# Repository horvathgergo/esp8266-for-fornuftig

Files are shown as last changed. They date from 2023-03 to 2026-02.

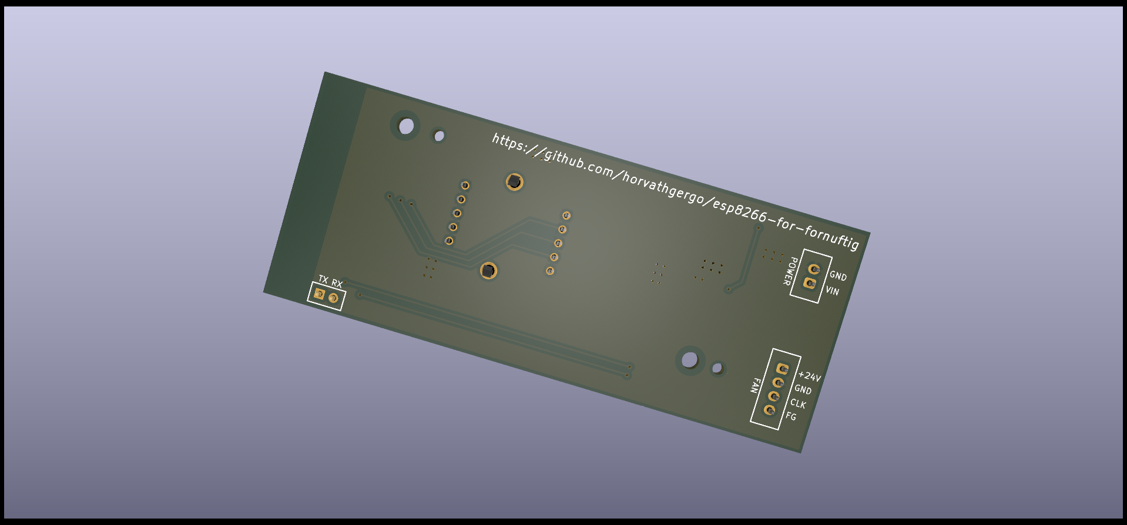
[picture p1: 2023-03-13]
Hardware/3D-model/3d-back-sw.png

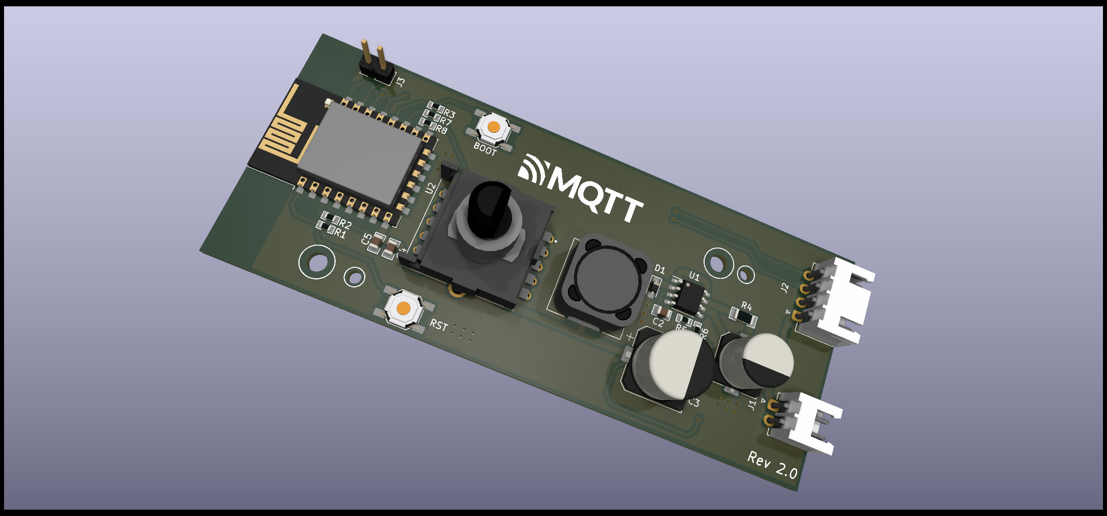
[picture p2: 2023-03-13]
Hardware/3D-model/3d-front-sw.png

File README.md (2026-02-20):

Newer version of the board based on an ESP32-C6 chip is available here: https://github.com/horvathgergo/esp32c6-for-fornuftig

# Smart Air Purifier (Project Fornuftig)

Custom PCB based on ESP12-F (ESP8266) wifi module that serves as a smart controller for IKEA Fornuftig Air Purifiers. It's embedded microcontroller enables you to incorporate your device to home automation systems (preferably to Home Assistant) or control it via custom mobile applications as it enjoys support from wide variety of firmwares. This project has been implemented in KiCad (hardware) and in Micropython (sofware).

About IKEA Fornuftig: It's a compact, 31x45 cm air purifier launched in the market around 2020. It effectively cleans the indoor air from harmful PM2.5 particles and pollen for a reasonable price (approx. EUR60). The device is optimised for medium-sized bedrooms and has three fan speed. 

Current status of the development: **Finalized**

Hardware: 
* [x] Schematic
* [x] Layout
* [x] BOM, CPL
* [x] 3D model 
* [x] Testing (v1.1 w/o switch)

Software:
* [x] MicroPython

## Hardware



PCB is a bit larger than the original one (98x40 mm) with mounting holes placed on it, thus it is supposed to fit just fine inside the plastic housing. Power supply of the fan is +24V, 0.8A. The board has a MC34063DR switching voltage regulator that provides the necessary power (+3v3, avg 70mA, peak >500mA) for the wifi module. This version (v2.0) of the board is designed with a rotary switch. To avoid unnecessary costs and save some space on the board physical filter reset button is not incorporated in this version as this function can be easily achieved through software side. 

The Purifier has a 4-pin PWM fan with +24VDC, 0.5A. The pins are power, ground, clk, fg. Clk is a control pin and fg is the tacho pin for feedback purposes. The fan operates with a constant duty cycle of 50% and variable frequency between ca. 1-300Hz.

MCU programming: the board supports only UART programming via TX, RX pin headers (as no USB interface), thus USB to TTL converter is necessary to upload your firmware. It is recommended to supply the module via VIN and GND pins during initial setup. It is compatible with +5-24V supply (note: in serial bootloader mode you need to supply at least +5V. Standard +3v3 won't work as you may experience some voltage drop via the buck converter so make sure to provide enough voltage during flashing. Supplying +5V won't hurt the ESP as the VIN pin of the board is not directly connected to chip). Boot button is located on the right side of the wifi module.

Tested first version of the board w/o rotary switch:



BOM: Most of the chosen components are considered to be basic/standard parts at LCSC, however there are some extended components on the list (two large caps, inductor, esp, jst connectors and uart pin headers).

## Software

The software for Fornuftig has been developed in Micropython. It enables the device to be controlled via mqtt while exploits Home Assistant mqtt autodiscovery features that provides with a smooth (almost zero config) setup process.

More detailed description is available in this repo: https://github.com/horvathgergo/uPurifier

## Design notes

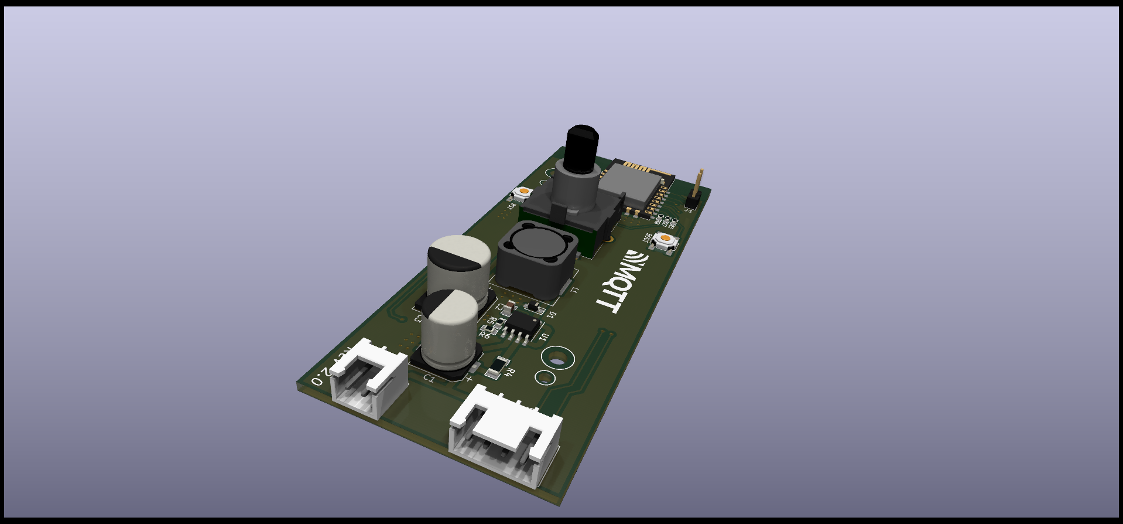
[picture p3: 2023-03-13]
Hardware/3D-model/3d-front2-sw.png

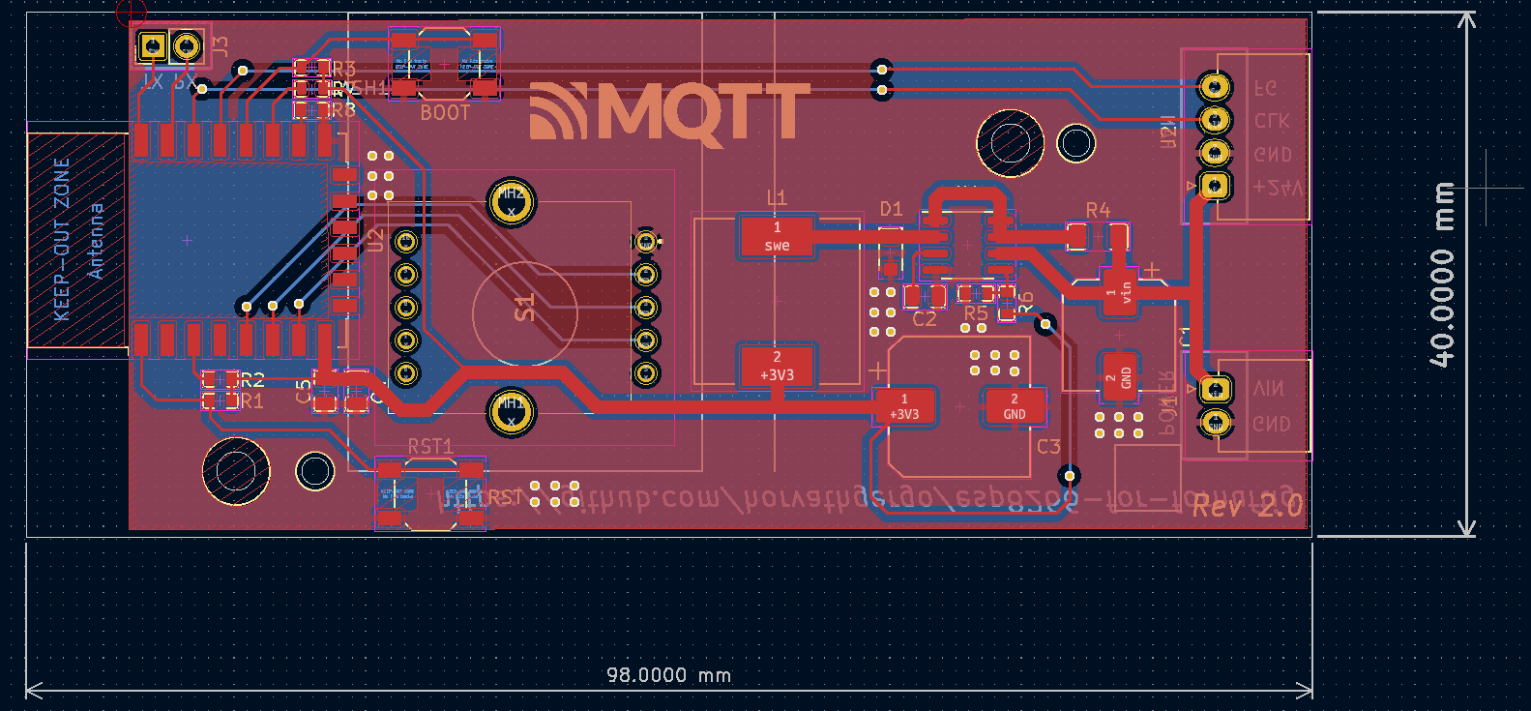
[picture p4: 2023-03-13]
Hardware/Air-Purifier-Fornuftig-Layout.png

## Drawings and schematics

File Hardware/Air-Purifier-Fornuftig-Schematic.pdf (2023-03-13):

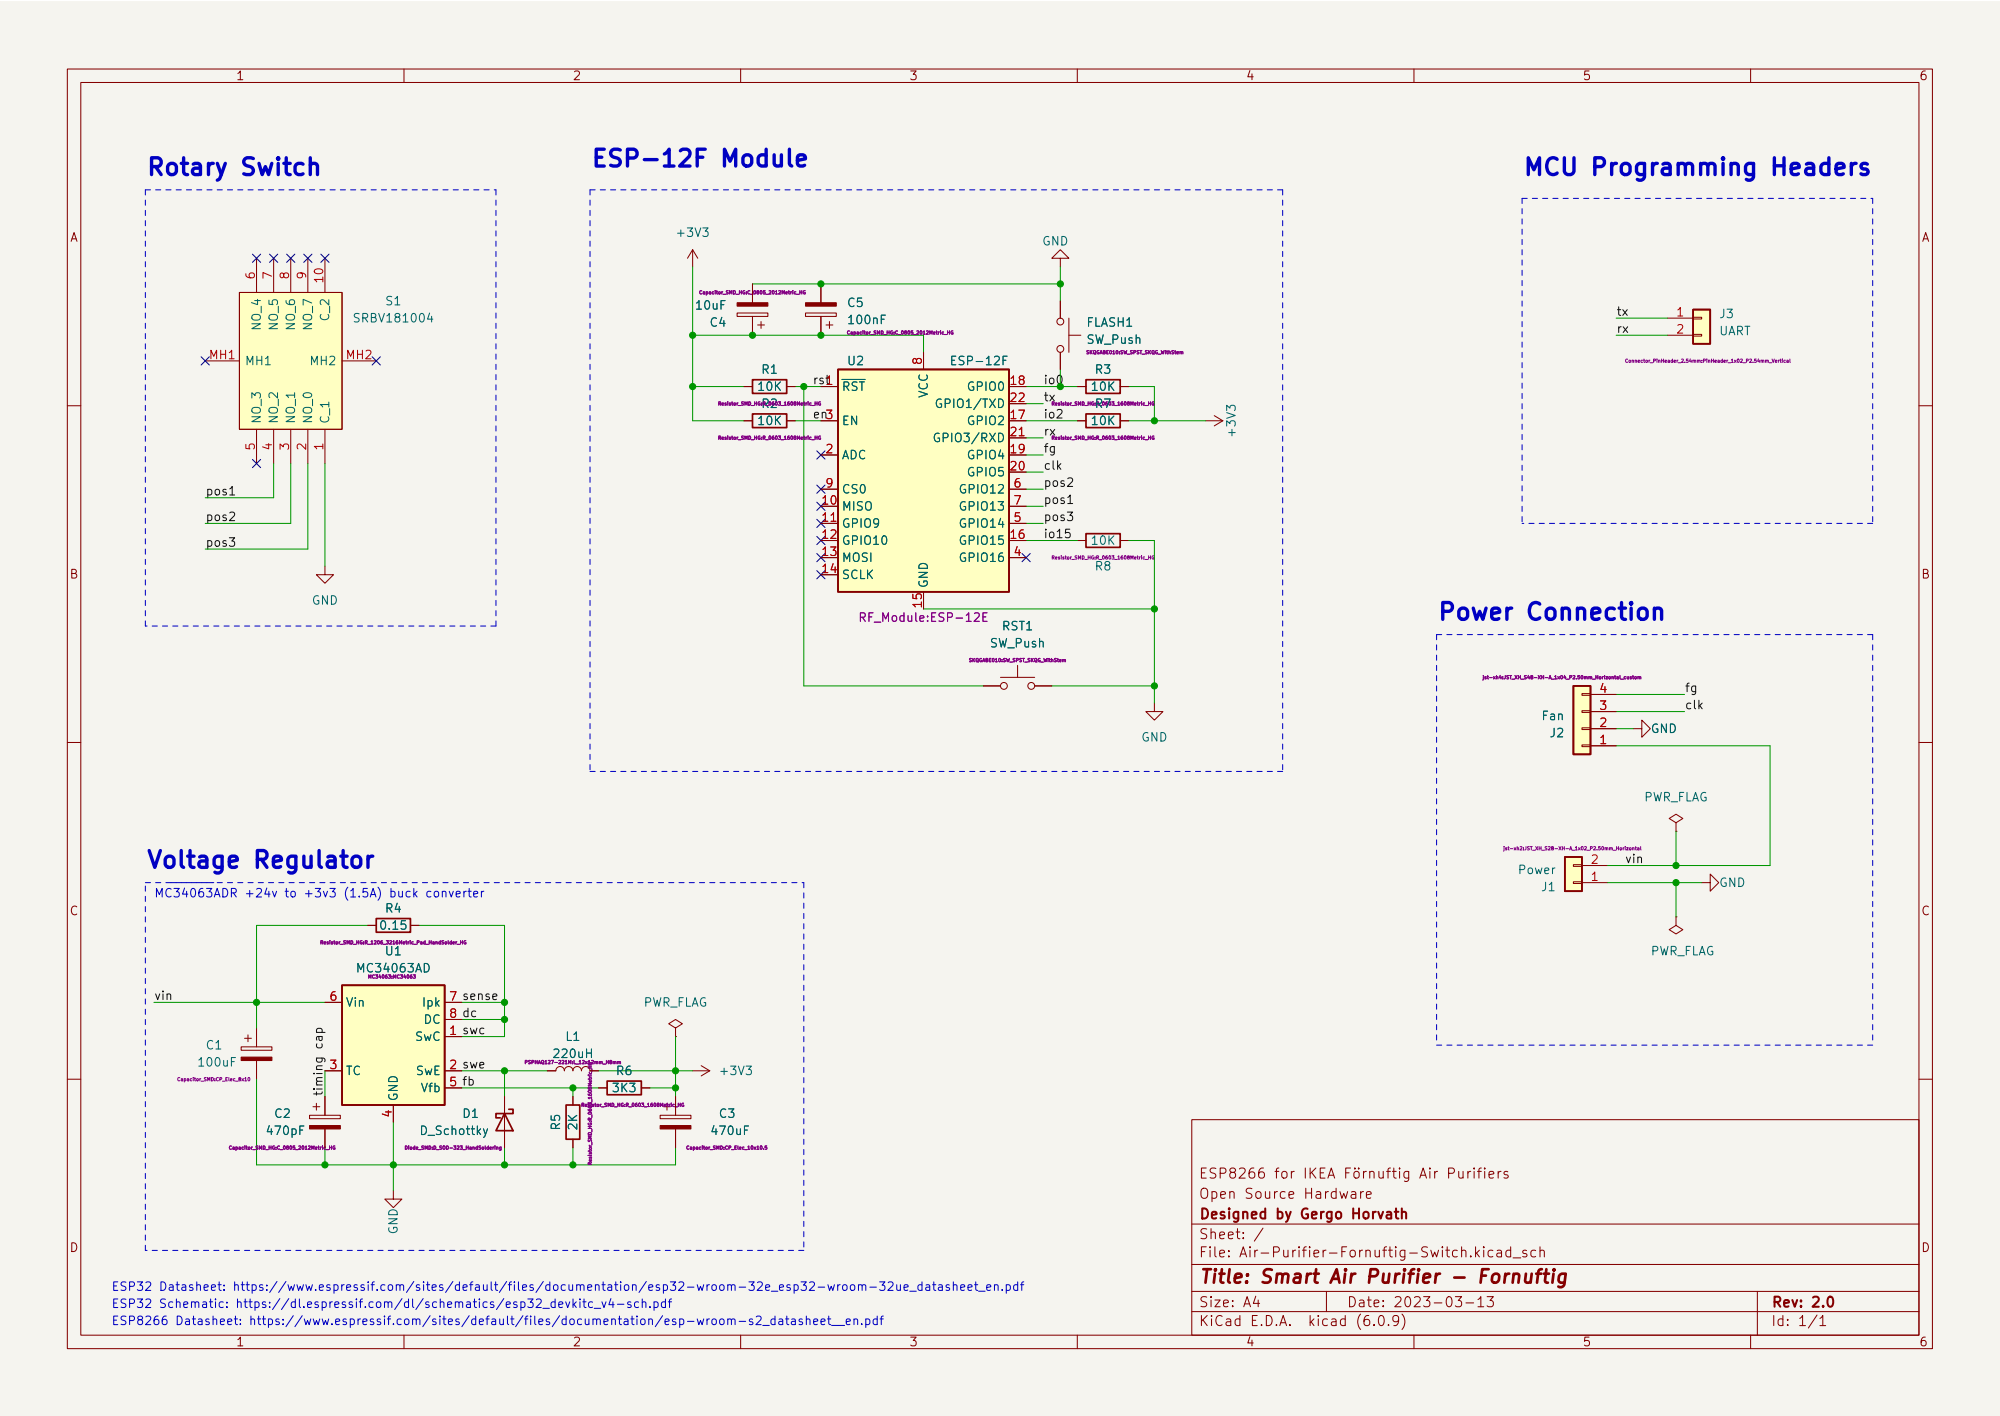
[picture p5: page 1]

Open Source Hardware
File: Air-Purifier-Fornuftig-Switch.kicad_sch Sheet: / Designed by Gergo Horvath

Id: 1/1 Title: Smart Air Purifier - Fornuftig

ESP32 Datasheet: https://www.espressif.com/sites/default/files/documentation/esp32-wroom-32e_esp32-wroom-32ue_datasheet_en.pdf
ESP32 Schematic: https://dl.espressif.com/dl/schematics/esp32_devkitc_v4-sch.pdf
ESP8266 Datasheet: https://www.espressif.com/sites/default/files/documentation/esp-wroom-s2_datasheet__en.pdf

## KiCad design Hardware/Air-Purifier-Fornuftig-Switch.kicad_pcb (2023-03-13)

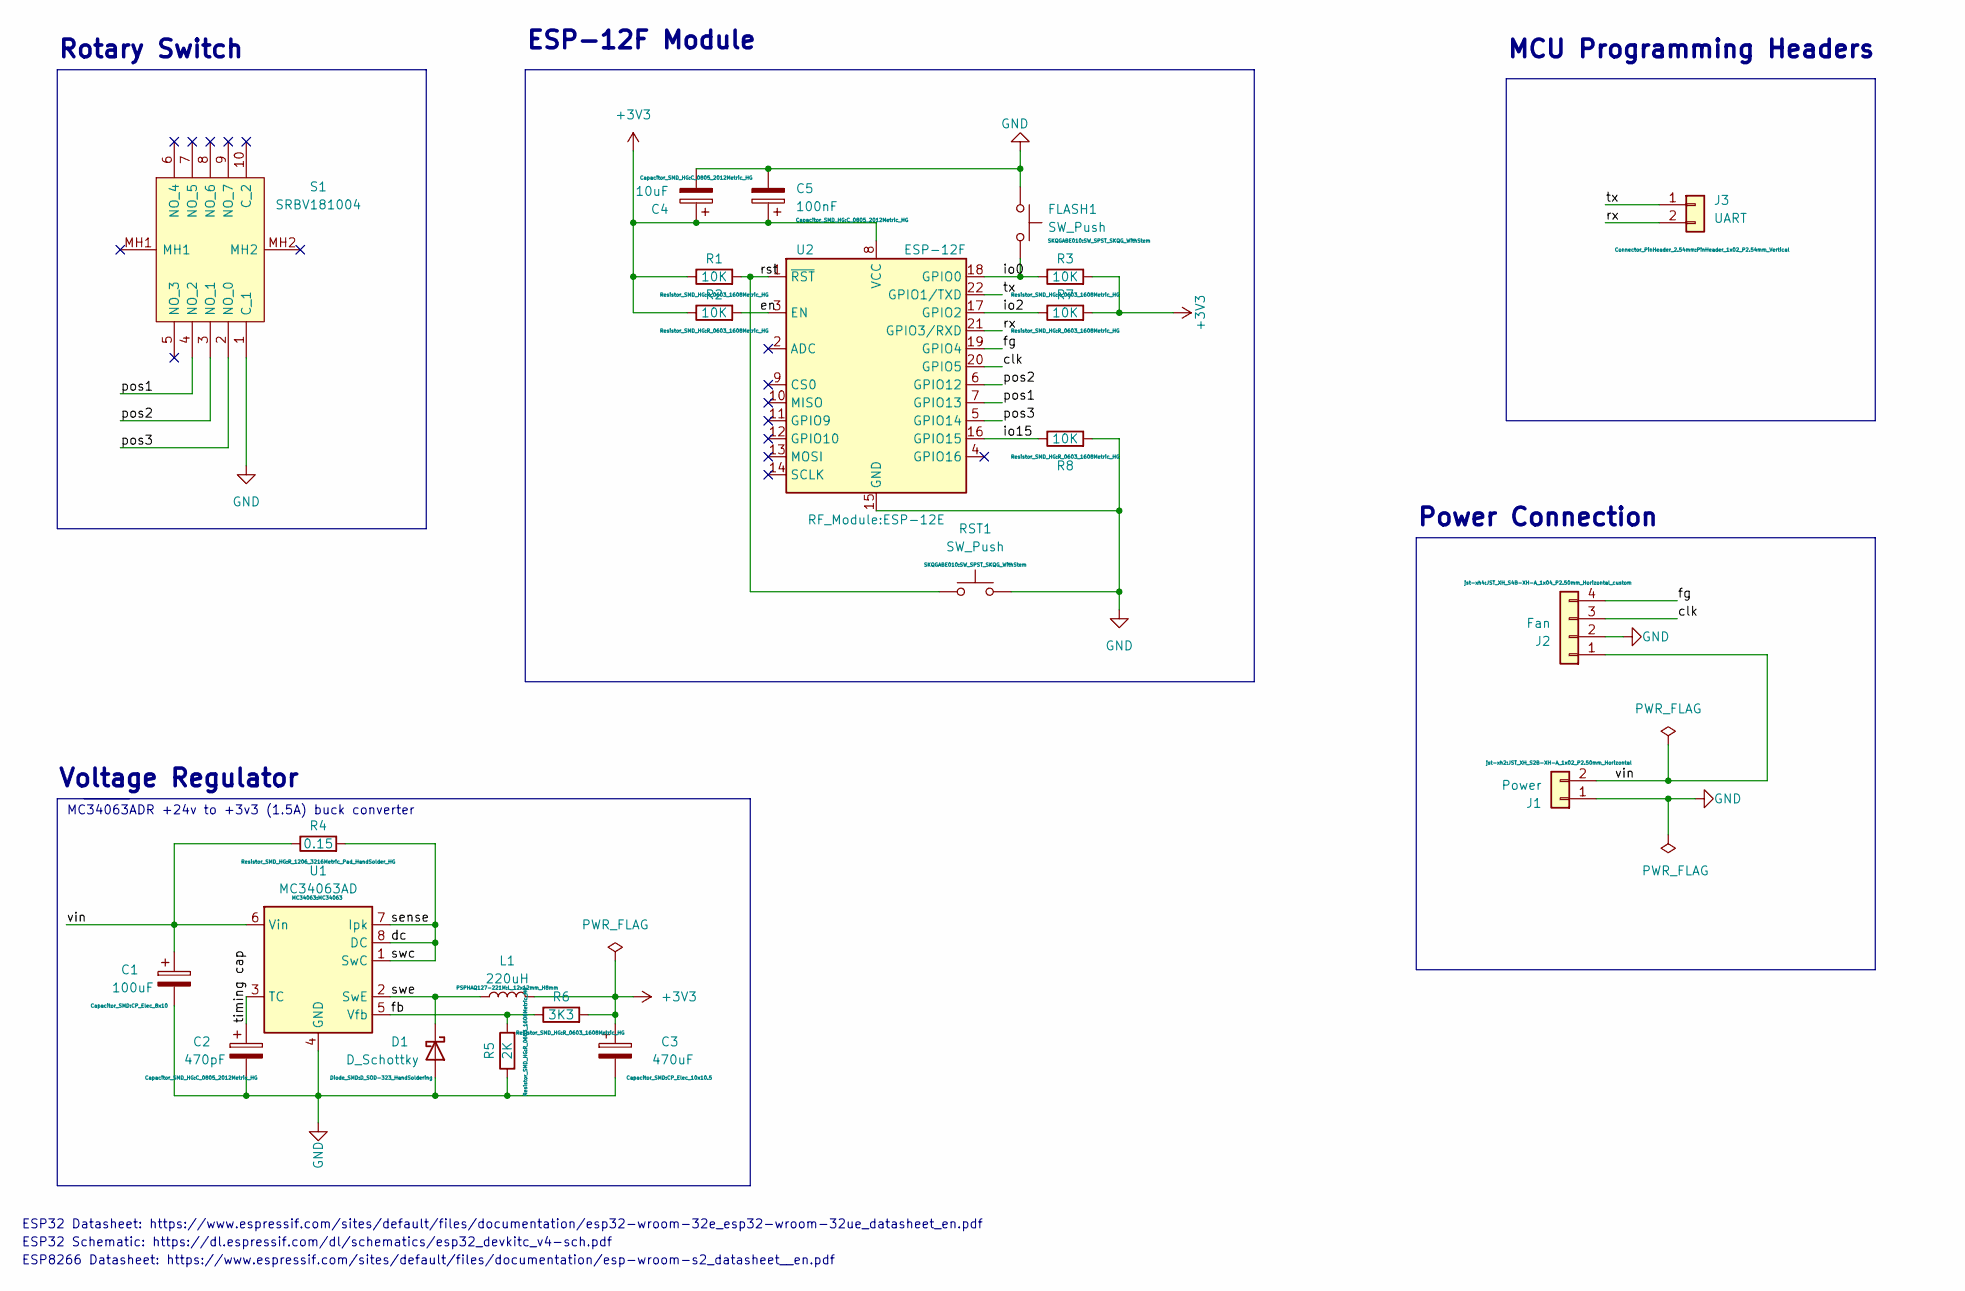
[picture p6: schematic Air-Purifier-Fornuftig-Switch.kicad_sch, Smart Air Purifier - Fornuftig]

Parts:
C1: 100uF; CP_Elec_8x10; LCSC C445063
C2: 470pF; C_0805_2012Metric_HG; LCSC C1743
C3: 470uF; CP_Elec_10x10.5; LCSC C72518
C4: 10uF; C_0805_2012Metric_HG; LCSC C15850
C5: 100nF; C_0805_2012Metric_HG; LCSC C28233
D1: D_Schottky; D_SOD-323_HandSoldering; LCSC C191023
FLASH1: SW_Push; SW_SPST_SKQG_WithStem; LCSC C318884
J1: Power; JST_XH_S2B-XH-A_1x02_P2.50mm_Horizontal
J2: Fan; JST_XH_S4B-XH-A_1x04_P2.50mm_Horizontal_custom
J3: UART; PinHeader_1x02_P2.54mm_Vertical
L1: 220uH; L_12x12mm_H8mm; LCSC C10151
R1, R2, R3, R7, R8: 10K; R_0603_1608Metric_HG; LCSC C25804
R4: 0.15; R_1206_3216Metric_Pad_HandSolder_HG; LCSC C247454
R5: 2K; R_0603_1608Metric_HG; LCSC C22975
R6: 3K3; R_0603_1608Metric_HG; LCSC C22978
RST1: SW_Push; SW_SPST_SKQG_WithStem; LCSC C318884
S1: SRBV181004; SRBV141404; Manufacturer_Part_Number SRBV181004; Mouser Part Number 688-SRBV181004
U1: MC34063AD; MC34063; LCSC C32078
U2: ESP-12F; ESP-12E; LCSC C82891

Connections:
+3V3: C3.1, C4.1, C5.1, L1.2, R1.1, R2.1, R3.2, R6.2, R7.2, U2.8 (VCC)
/clk: J2.3, U2.20 (GPIO5)
/dc: R4.2, U1.1 (SwC), U1.7 (Ipk), U1.8 (DC)
/en: R2.2, U2.3 (EN)
/fb: R5.2, R6.1, U1.5 (Vfb)
/fg: J2.4, U2.19 (GPIO4)
/io0: FLASH1.2, R3.1, U2.18 (GPIO0)
/io2: R7.1, U2.17 (GPIO2)
/io15: R8.1, U2.16 (GPIO15)
/pos1: S1.4 (NO_2), U2.7 (GPIO13)
/pos2: S1.3 (NO_1), U2.6 (GPIO12)
/pos3: S1.2 (NO_0), U2.5 (GPIO14)
/rst: R1.2, RST1.1, U2.1 (~RST)
/rx: J3.2, U2.21 (GPIO3/RXD)
/swe: D1.1 (K), L1.1, U1.2 (SwE)
/timing cap: C2.1, U1.3 (TC)
/tx: J3.1, U2.22 (GPIO1/TXD)
/vin: C1.1, J1.2, J2.1, R4.1, U1.6 (Vin)
GND: C1.2, C2.2, C3.2, C4.2, C5.2, D1.2 (A), FLASH1.1, J1.1, J2.2, R5.1, R8.2, RST1.2, S1.1 (C_1), U1.4 (GND), U2.15 (GND)

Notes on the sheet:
Rotary Switch
ESP32 Schematic: https://dl.espressif.com/dl/schematics/esp32_devkitc_v4-sch.pdf
MC34063ADR +24v to +3v3 (1.5A) buck converter
ESP-12F Module
ESP8266 Datasheet: https://www.espressif.com/sites/default/files/documentation/esp-wroom-s2_datasheet__en.pdf
ESP32 Datasheet: https://www.espressif.com/sites/default/files/documentation/esp32-wroom-32e_esp32-wroom-32ue_datasheet_en.pdf
MCU Programming Headers
Power Connection
Voltage Regulator

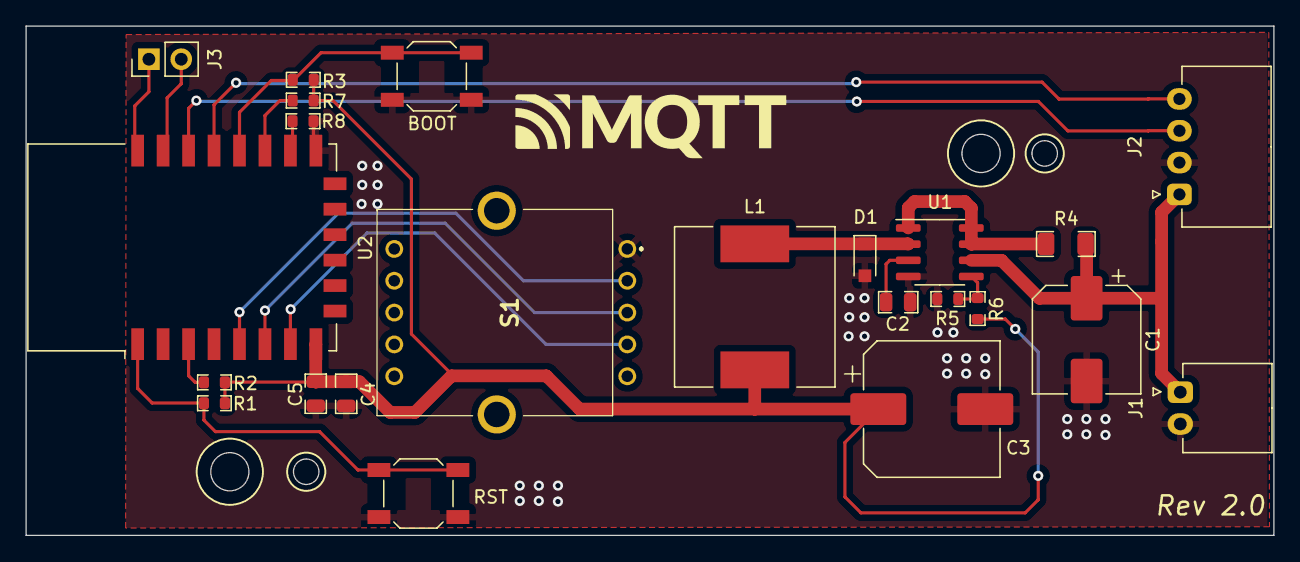
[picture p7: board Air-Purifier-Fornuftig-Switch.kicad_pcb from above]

Board: 2 copper layers, 98.0 x 40.0 mm, 23 parts (0 on the bottom side), 19 nets.

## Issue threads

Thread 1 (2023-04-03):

Fuse

Szewcson, 2023-04-03:
What was the reason for removing fuse that was present in previous version?

horvathgergo, 2023-04-03:
> What was the reason for removing the fuse that was present in the previous version?

Mainly because the manufacturer I chose had limited and expensive stock. Also, it wasn't really necessary as the switching voltage regulator has a current sense resistor that opens circuit between VIN and ESP and stops current flow in case.

It's not inevitable but maybe a placeholder for a fuse (in a form of a zero ohm resistor) would be a reasonable compromise between VIN and +24V.

Szewcson, 2023-04-03:
I'm thinking about adding it, and also a LED in place of the original one. Are you open to contribution?

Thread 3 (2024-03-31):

Whining coil noise

simonepsp, 2024-03-31:
Hello everyone!
First all, thank you for this great project. I've been looking for a way to develop a cheap, open source and esp based air purifier for a while and this project made it possible!

I've purchased 5 built PCBs from JLPCB and everything has been working so far.
The only disturbing issue is a constant whining coil / high pitch noise (likely) coming from the ESP32 board or the capacitors. The issue only seem to occur only when the board is powered directly with the purifier's +24V cable and not when supplied +5V.

Have you experienced / noticed anything similar?
Thanks a lot!

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

simonepsp, 2024-04-05:
> Yes, I can confirm I have the same. Personally I only notice the coil whine in my right ear, my left ear seems to be "older" ;) Not sure how this can be fixed to be honest.

hahah I see... I've covered the power inductor in the middle of the PCB with hot glue and looks like the noise is gone.
I'll keep on eye on it for any heat dissipation issue

joaopbnogueira, 2024-06-24:
@simonepsp I'm facing the same problem but I ended up slapping 1 layer of Kilmat deadening automotive insulation mat on the bottom of the PCB and 2 layers on top making sure to get a tight seal around the components. So far so good.

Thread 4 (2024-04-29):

Unable to erase flash

joaopbnogueira, 2024-04-29:
Hi, this might be a noob question but I can't seem to be able to erase the flash using `esptool.py`

- I'm using a USB-to-TTL adapter (with PL2303) and 5VDC (https://mauser.pt/catalog/product_info.php?products_id=096-7521)
- When pluggin in the VDC, I get a short blink of the esp led
- When running `python -m serial.tools.miniterm "$PORT"` and hitting the RST button get random chars on the console (using the recommended baudrate of 74880)
- When running `esptool.py --port "$PORT" erase_flash` I get `Serial data stream stopped: Possible serial noise or corruption.`

Any tips? Thank you!

joaopbnogueira, 2024-05-20:
I checked the GND and VND pins on the esp-12f and they were a bit low with the 5V supply (around 3.0V), using the device's 24V raised it to the target 3.3V, but still get the same corruption error. Any hint to debug? Also tested with an FT232R and 9600 baud rate...

horvathgergo, 2024-05-20:
Have you tried flashing ESPHome? It worked for others, and if it works for you too, that's a hint to exclude a possible hardware error

joaopbnogueira, 2024-06-18:
hey @horvathgergo I was able to sort this out.

For reference and maybe to help others these were the steps:
- Connect an external power supply (not using the TTL/serial adapter for power) and verify 3.3V on the ESP-12F
- Make sure that GND for the TTL adapter is shared with GND from the power supply (short)
- Read esp-12f datasheet and notice GPIO 15 should be down for flashing
- Hold boot button, hold reset, release reset, release boot.
- Verify that GPIO15 is down 0V to GND
- Flash using https://web.esphome.io/ straight from the browser.
- Success!

Closed 2024-06-18.

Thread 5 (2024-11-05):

Missing BOM

marrold, 2024-11-05:
Hi,

Thanks for a great project. I'd like to get JLCPCB to manufacture the board but I can't seem to find the BOM or CPL file - do you have them?

Thanks

kamko, 2025-01-02:
It's provided in release archive
https://github.com/horvathgergo/esp8266-for-fornuftig/releases/tag/v2.0.0

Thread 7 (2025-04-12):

Value of R4 resistor?

nocodeman55, 2025-04-12:
So guys

Do i read this correct

BOM says 0.15

Is that 0.15 Ω ?

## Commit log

2023-01-30 Add BOM, CPL, Gerber
    [BOM.csv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]
2023-01-30 Add Schematic-v1.1
2023-03-13 add v2.0 KiCad
    [Air-Purifier-Fornuftig-Switch.kicad_pcb, Air-Purifier-Fornuftig-Switch.kicad_sch]
2023-03-13 add Schematic v2.0
